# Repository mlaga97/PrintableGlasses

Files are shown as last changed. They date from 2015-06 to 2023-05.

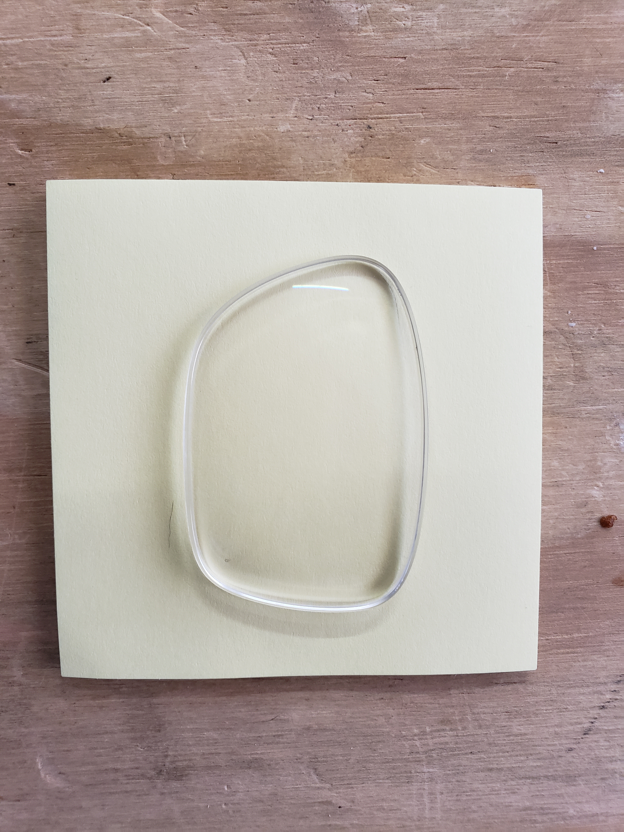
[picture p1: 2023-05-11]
Frames/20230323_154101.jpg

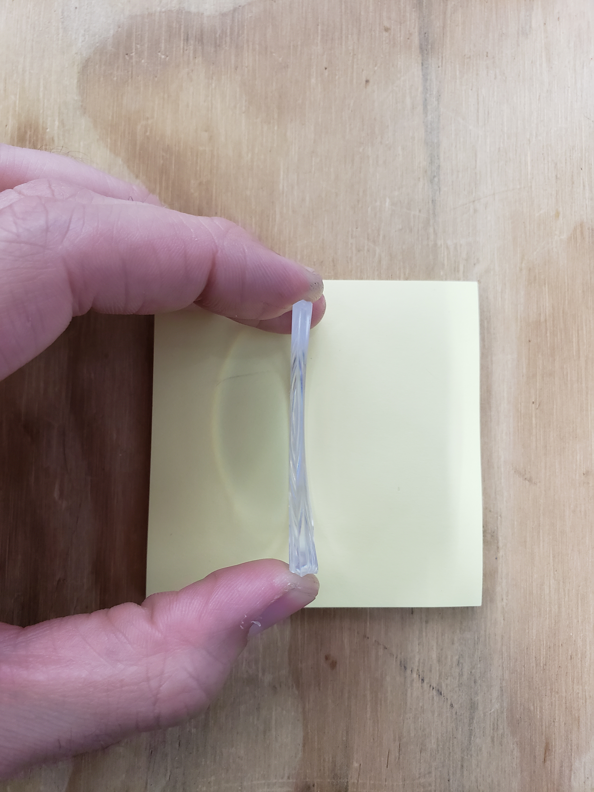
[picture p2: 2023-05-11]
Frames/20230323_154824.jpg

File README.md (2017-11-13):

# Printable Glasses
3d-printable glasses frames that are parametrically generated around arbitrary lens shapes.

# Software Tools Needed
1. [OpenSCAD](http://www.openscad.org/)
2. A 2D CAD Package (e.g. [LibreCAD](https://github.com/LibreCAD/LibreCAD))

# Hardware Needed
1. A 3D Printer
2. 2x M3x20mm Socket Head Cap Screws
3. 2x M3 Nut

# Vague Instructions
1. Replace `Frames/LeftLensFrontView.dxf` and `Frames/LeftLensTopView.dxf` with scaled outlines of lens shape in units of mm.
2. Build Frames/Frame.scad to generate a Frame.stl file and print. If lens does not fit, use of a scaling factor may be appropriate.
3. Select the appropriate GlassesArm from `Arms/GlassesArm_[LENGTH]mm.stl` and print 2 copies.

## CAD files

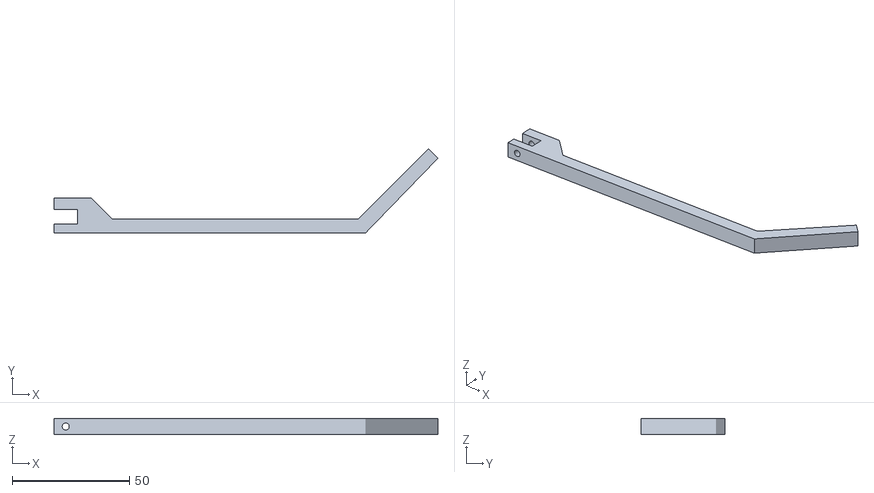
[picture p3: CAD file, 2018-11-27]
Arms/GlassesArm_130mm.stl
164.0 x 36.0 x 7.00

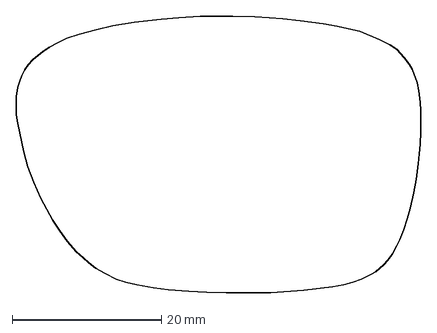
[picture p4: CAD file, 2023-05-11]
Frames/RightLensFrontView.dxf
54.2 x 37.1 mm

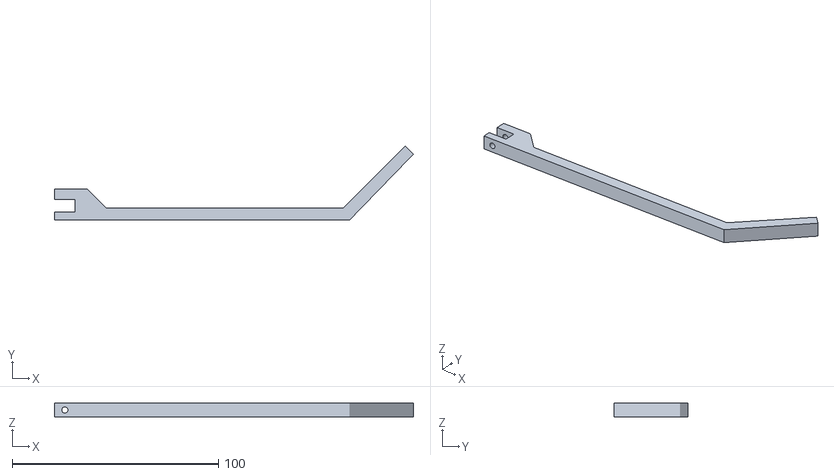
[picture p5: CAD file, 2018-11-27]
Arms/GlassesArm_140mm.stl
174.0 x 36.0 x 7.00

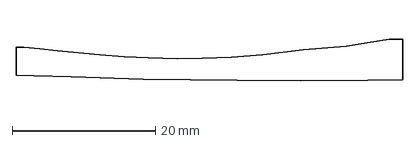
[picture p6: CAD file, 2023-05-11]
Frames/RightLensTopView.dxf
54.0 x 5.75 mm

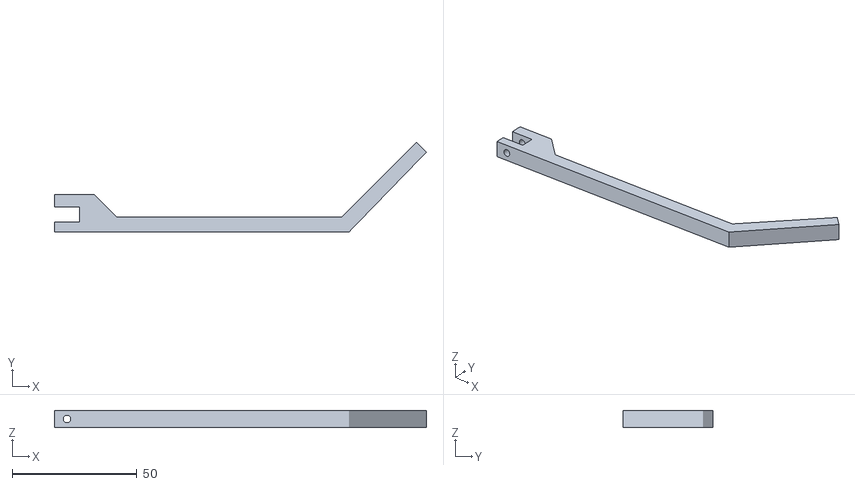
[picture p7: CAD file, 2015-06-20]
Arms/GlassesArm_115mm.stl
149.0 x 36.0 x 7.00

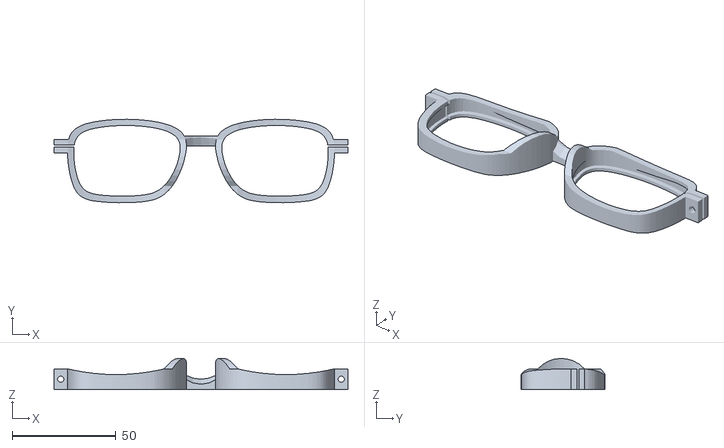
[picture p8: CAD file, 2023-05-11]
Frames/Frame.stl
141.4 x 40.2 x 15.0

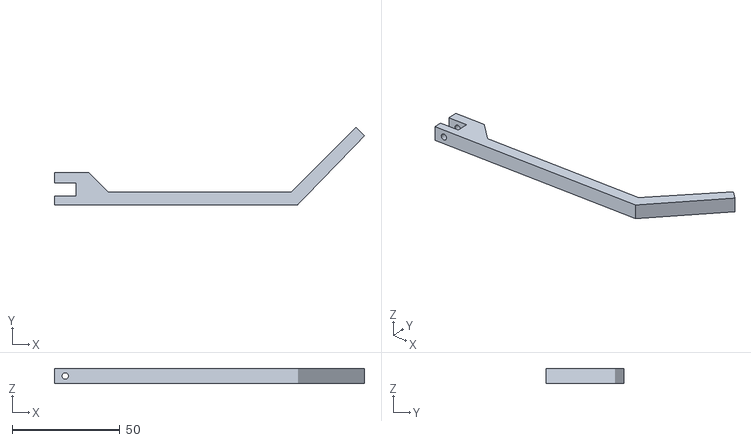
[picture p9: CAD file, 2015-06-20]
Arms/GlassesArm_110mm.stl
144.0 x 36.0 x 7.00

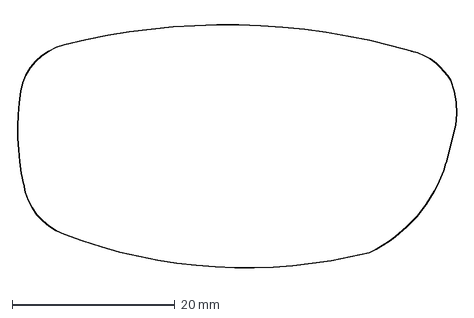
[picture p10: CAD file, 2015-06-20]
Frames/Frame Test.dxf
54.4 x 32.2 mm

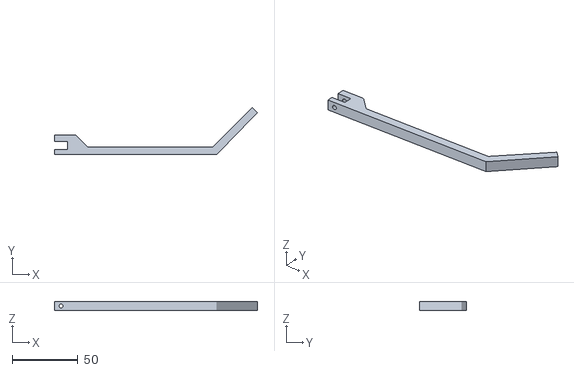
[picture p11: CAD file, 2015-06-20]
Arms/GlassesArm_120mm.stl
154.0 x 36.0 x 7.00

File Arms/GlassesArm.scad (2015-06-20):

difference() {
	linear_extrude(7)
		import("GlassesArm_115mm.dxf");
	translate([5,17,3.5])
		rotate([90,0,0])
			cylinder(r=1.5,h=25,$fn=24);
}

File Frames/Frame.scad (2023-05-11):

lensWidth = 54;
lensHeight = 36;

parameter_a = 1.5;
parameter_b = 1.5;
parameter_c = -11.95;
parameter_d = 0.22;

parameter_e = 9;
parameter_f = 47;
parameter_g = 17;
parameter_h = 1.3;

parameter_i = 100;

// Right lens
module lens() {
	intersection() {
		linear_extrude(height=15)
			import("RightLensFrontView.dxf",$fn=250);
		translate([0,20,0])
			rotate( [90,0,0] )
				linear_extrude(height=50)
					import("RightLensTopView.dxf",$fn=250);
	}
}

module lens_case() {
  translate([lensWidth/2, (lensHeight+parameter_a*2)/lensHeight * -(parameter_c + lensHeight/2), 0]) // TODO: Y is probably wrong
    difference() {
      union() {
        linear_extrude(height = 20)
          scale([(lensWidth+parameter_a*2)/lensWidth,(lensHeight+parameter_a*2)/lensHeight])
            translate([-lensWidth/2, parameter_c + lensHeight/2, 0])
              import("RightLensFrontView.dxf",$fn=250);
      }
      translate([0, 0, -1])
        linear_extrude(height=100)
          scale([(lensWidth-parameter_b*2)/lensWidth,(lensHeight-parameter_b*2)/lensHeight])
            translate([-lensWidth/2, parameter_c + lensHeight/2, 0])
              import("RightLensFrontView.dxf",$fn=250);	
    }
}

module lens_assembly() {
  intersection() {
    difference() {
      union() {
        lens_case();
        translate([lensWidth, -6.5/2, 0])
          cube([parameter_a + parameter_d + 6.5, 6.5, 10]);
      }

      translate([0, 0, 1.5]) // TODO: Parameterize
        scale([1, 1, 1.2]) // TODO: Parameterize
          lens();

      translate([lensWidth/2, -1/2, -1])
        cube([lensWidth, 1, 10 + 2]);

      translate([lensWidth + parameter_a + parameter_d + 6.5/2, 0, 5])
        rotate([90, 0, 0])
          cylinder(d = 3, h = 25, $fn = 24, center = true);

      intersection() {
        translate([(lensWidth - parameter_e + parameter_a + parameter_d)/2 + parameter_e, 20, 10 + sqrt(pow(parameter_i, 2) - pow((lensWidth - parameter_e + parameter_a + parameter_d)/2, 2))]) // TODO: Parameterize
          rotate([90, 0, 0])
            cylinder(r = parameter_i, h = 100, $fn=120);

        translate([parameter_e, -50, 0])
          cube([lensWidth - parameter_e + parameter_a + parameter_d, 100, 100]);
      }
    }

    // TODO: Parameterize
    union() {
      translate([-10, -10 + 2, -30/2 + 10 + 5])
        rotate([0, 90, 0])
          cylinder(d = 30, h = 20);
      translate([-10, -50, 0])
        cube([100, 100, 10]);
    }

  }
}

module bridge() {
	difference() {
		union() {
			translate([0,4,9/2])
				cube([parameter_g - parameter_a/2, 4, 9],center=true);
			translate([0,6,9/2])
				cube([parameter_g - parameter_a/2 + parameter_h, 2, 9],center=true);
		}

		union() {
			translate([0,-10,15-2])
				rotate([-60,0,0])
					cylinder(r=15,h=20,$fn=24);

			translate([0,15,22-2])
				rotate([90,0,0])
					cylinder(r=15,h=20,$fn=24);
		}
	}
}

difference() {
	// Raw Frames
	union() {
    for (m = [0, 1])
      mirror([m, 0, 0])
        translate([parameter_g/2,0,0])
          lens_assembly();

		// Bridge
    translate([0, -2, 0])
      bridge();
	}
}

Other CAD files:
Arms/GlassesArm_110mm.dxf
Arms/GlassesArm_115mm.dxf
Arms/GlassesArm_120mm.dxf
Arms/GlassesArm_130mm.dxf
Arms/GlassesArm_140mm.dxf

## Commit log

2015-06-20 Add original files
    [Frame Test.dxf, Frame.scad, Frame.stl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]
2015-11-24 Fix deprecated usage of linear_extrude.
    [Frame.scad]
2015-11-24 Fix asymmetery due to off-by-one error.
    [Frame.scad]
2016-06-27 Improve fit of frame around lenses.
    [Frame.scad, Frame_largerlenses.stl]
2018-11-27 Add additional arm lengths
    [GlassesArm_130mm.dxf, GlassesArm_130mm.stl, GlassesArm_140mm.dxf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]
2023-05-11 Refactor for new lenses + break out more knobs to tweak
    [Frame.scad, Frame.stl, Frame_largerlenses.stl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]
